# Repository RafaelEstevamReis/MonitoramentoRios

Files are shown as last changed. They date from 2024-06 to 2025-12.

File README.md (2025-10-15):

# MonitoramentoRios

Repositório do Projeto de Monitoramento de Rios

Acesse o sistema que monitora Rolante no Rio Grande do Sul: [Acessar](https://rios.bitcoineaqui.com.br/)

## Objetivo

Este repositório tem por objetivo desenvolver uma stack de Software e Hardware para monitoramento atmosférico, pluvial e fluvial, com o objetivo de publicar de forma aberta dados precisos a todos que precisarem.

## Arquitetura

O é Sistema altamente integrável, permitindo tanto o uso do Hardware desenvolvido aqui quanto integração de fontes externas, além de ser distribuído replicado em locais geograficamente afastados para redundância e proteção. 

Focando em baixo custo a Placa-mãe foi desenvolida pelo projeto para utilização de sensores amplamente disponíveis

### Detalhes do Hardware

Hardware baseado em ESP32 utilizando PCB customizada para o ambiente úmido da beira de rios mas compatível com DevKits como NodeMCU

Firmware baseado na Stack ESP-Home pela melhor curva de aprendizado de novos colaboradores

### Detalhes do Software

Backend redundante e integrado, recebe dados diretamente de estações, de servidor MQTT externo, de outros Backends, e integrações de sistemas externos

Frontend em Html/JS puro para leveza a simplicidade de treinamento e manutenção

## Agradecimentos Especiais

* A todas as doações em Bitcoin para o projeto [Bitcoin é Aqui](https://bitcoineaqui.com.br) que financiaram a pesquisa e desenvolvimento do projeto
* Ao [Geoge Silva](https://github.com/nitroxgas) por lançar a ideia e desenvolver o primeiro protótipo

## Posso usar o software ou hardware que este repositório desenvolve?

SIM!, mas com ressalvas.

O objetivo deste projeto é compartilhar informações, porém há muitas entidades que coletam os dados e os fecham, tornando-os inúteis para um amplo acesso.
Portanto, se você compartilha seus dados, você pode usar os nossos; se você restringe seus dados, você não pode usar os nossos.

Leia mais abaixo o texto completo do licenciamento antes de contribuir ou utilizar este repositório.

## Como replicar na minha cidade?

Você pode tanto replicar o sistema aqui desenvolvido por conta como integrar ao sistema já mantido pelo Projeto

Para integrar sua cidade no sistema já existente entre em contato com o [Bitcoin é Aqui](https://bitcoineaqui.com.br) ou com a [ACISA de Rolante](https://acisarolante.com/)

## Licença

Este repositório está licenciado sob uma dupla licença (`MIT` e `Licença Restrita`). Leia atenciosamente antes de contribuir e usar os dados gerados por estes softwares e hardwares.

A licença geral é MIT. No entanto, se você coleta, fornece e/ou processa dados de monitoramento atmosférico, manancial, fluvial, pluvial ou semelhantes, está sujeito às seguintes condições: Se os dados que você coleta são fechados, privados, compartilhados com limitações de acesso ou licenciamento, possuem mecanismos de controle de acesso, e/ou limitações na forma de acesso, então você não pode acessar, visualizar, compartilhar, utilizar, ou divulgar os dados coletados e gerados por este repositório e suas derivações. Nestes casos, você está sujeito à `Licença Restrita`.

Adicionalmente, se você é órgão governamental ou à serviço do serviço público, você precisa pedir autorização prévia para o uso dos dados.

### Licença Restrita

~~~
Termos de Uso da Licença Restrita

Esta licença estabelece os termos sob os quais os dados coletados e processados  podem ser acessados. Ao acessar ou utilizar estes dados, você concorda com os seguintes termos:

1. Proibição de Uso:

Os dados fornecidos por este repositório não podem ser utilizados para qualquer finalidade, seja ela comercial ou não comercial.

2. Proibição de Modificação:

Você não tem permissão para modificar, adaptar, ou criar obras derivadas dos dados fornecidos por este repositório.

3. Proibição de Redistribuição:

Você não pode redistribuir, compartilhar, publicar, ou de qualquer forma disponibilizar os dados a terceiros.

4. Proibição de Acesso Automatizado:

O acesso automatizado aos dados (por exemplo, via scripts, bots, ou outras ferramentas de automação) é estritamente proibido.

5. Proibição de Análise e Processamento:

Qualquer forma de análise ou processamento adicional dos dados coletados por este repositório é estritamente proibida.

6. Confidencialidade:

Você deve manter a confidencialidade dos dados acessados e não deve divulgar, publicar, ou de qualquer forma tornar públicos esses dados.

7. Penalidades

Qualquer violação dos termos desta licença pode resultar em medidas legais, incluindo, mas não se limitando a, ações civis e criminais.

8. Acordo

Ao acessar ou utilizar os dados fornecidos por este repositório, você reconhece que leu, entendeu e concorda em cumprir todos os termos desta licença. Se você não concorda com estes termos, não deve acessar ou utilizar os dados.
~~~

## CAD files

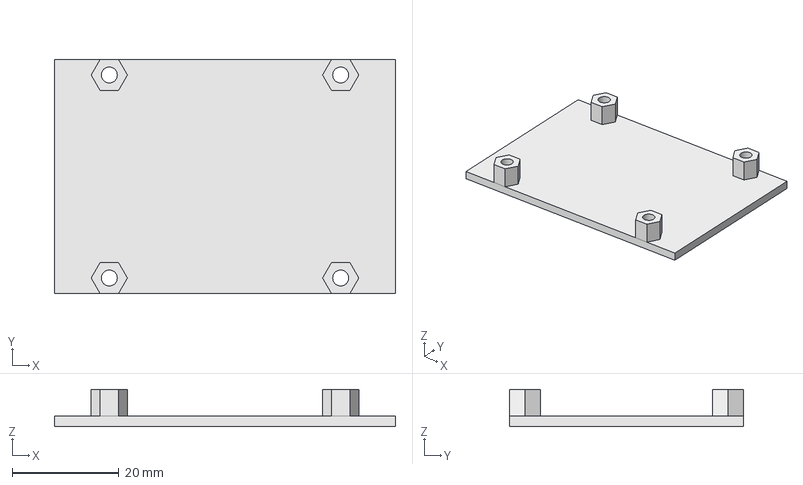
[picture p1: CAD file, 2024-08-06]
Hardware/Estação/Placa Mãe/Dev_1.1/Suporte/Suporte.FCStd
64.0 x 44.0 x 7.00 mm

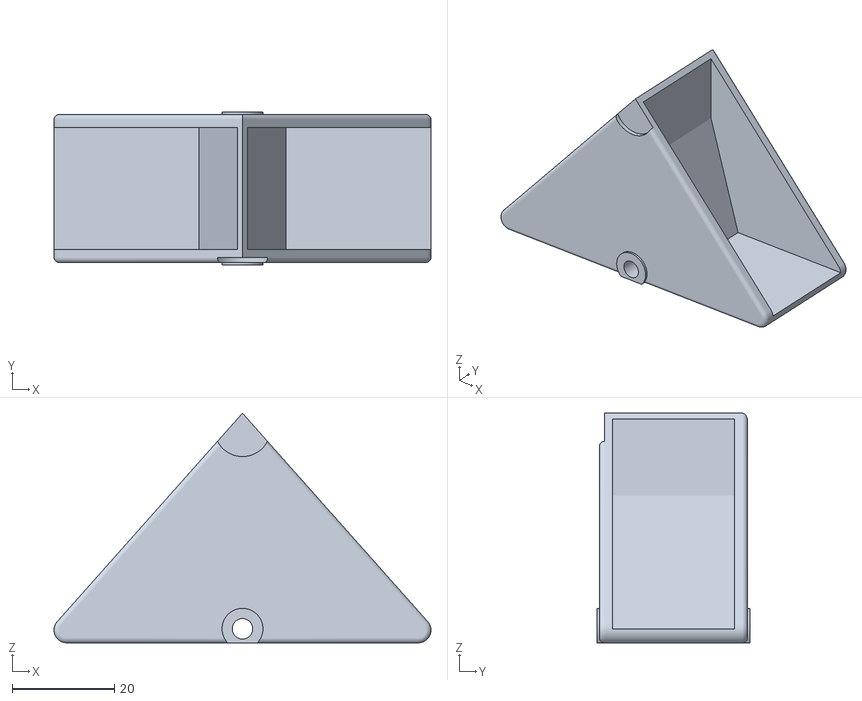
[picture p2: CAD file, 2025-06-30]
Hardware/Pluviômetro/3DP/Pluv_v0-Bucket.stl
73.9 x 30.0 x 45.0

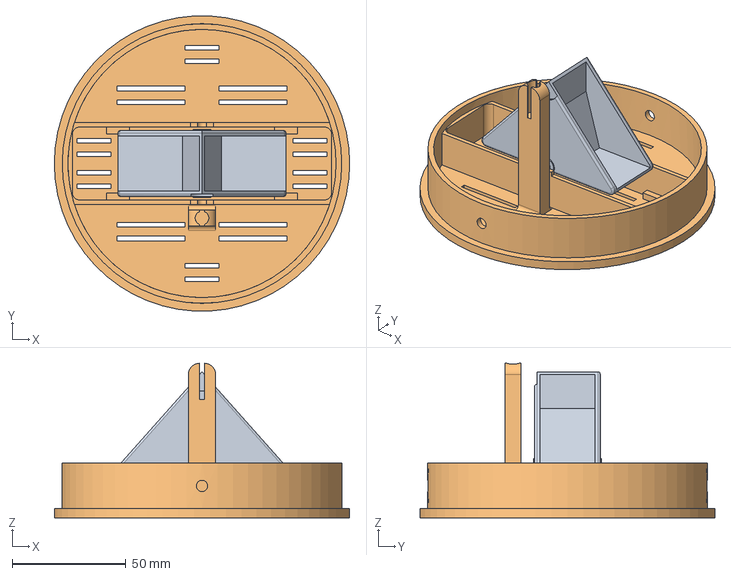
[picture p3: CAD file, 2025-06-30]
Hardware/Pluviômetro/3DP/Pluv_v0.FCStd
130.0 x 129.8 x 68.0 mm
Bucket
Base

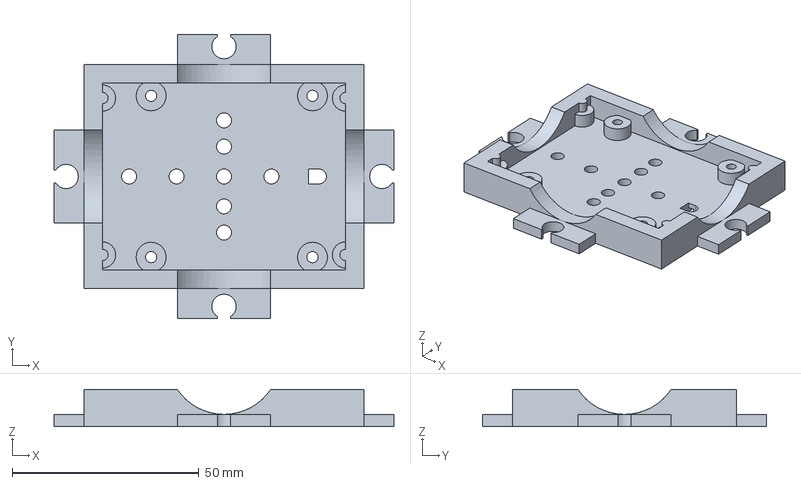
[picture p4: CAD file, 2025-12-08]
Montagem/Acessorios/SuportePlaca_v1.3.FCStd
91.0 x 76.0 x 10.0 mm

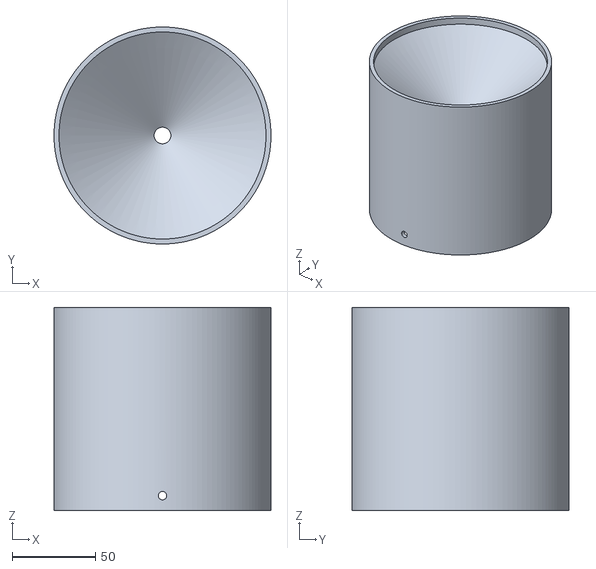
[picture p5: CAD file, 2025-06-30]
Hardware/Pluviômetro/3DP/Pluv_v0-Funnel.stl
130.0 x 130.0 x 121.8

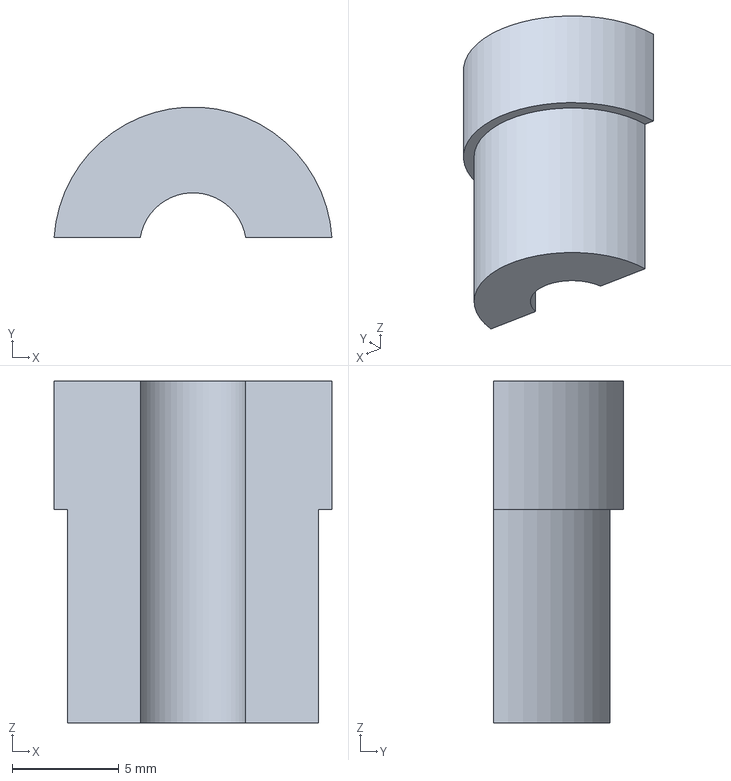
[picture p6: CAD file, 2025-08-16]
Montagem/Acessorios/SabotCabo.FCStd
13.0 x 6.10 x 16.0 mm

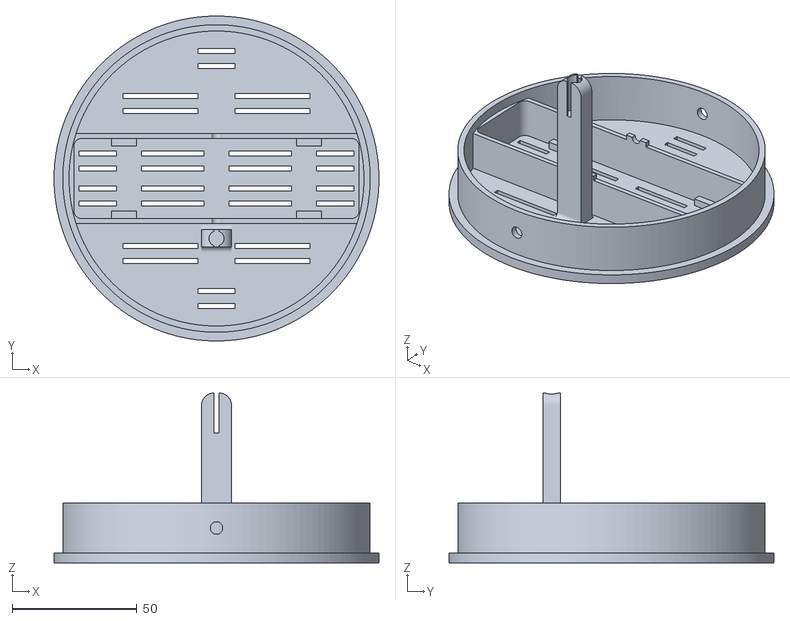
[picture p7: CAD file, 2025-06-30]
Hardware/Pluviômetro/3DP/Pluv_v0-Base.stl
130.0 x 130.0 x 68.0

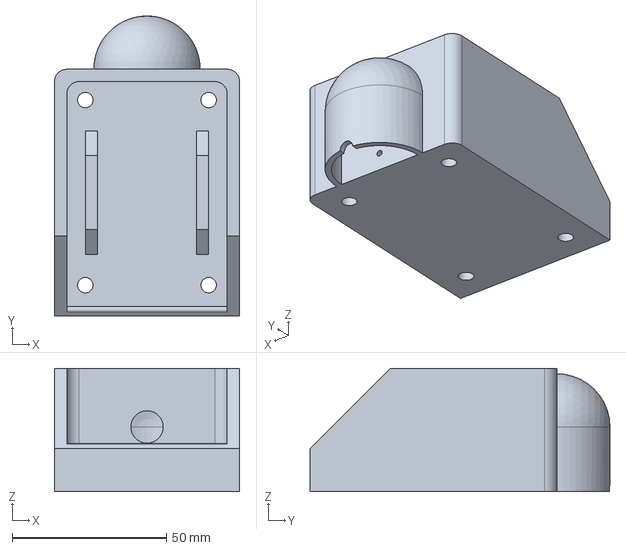
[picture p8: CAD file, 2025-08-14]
Montagem/Acessorios/SuporteBoia.FCStd
60.0 x 97.2 x 40.0 mm

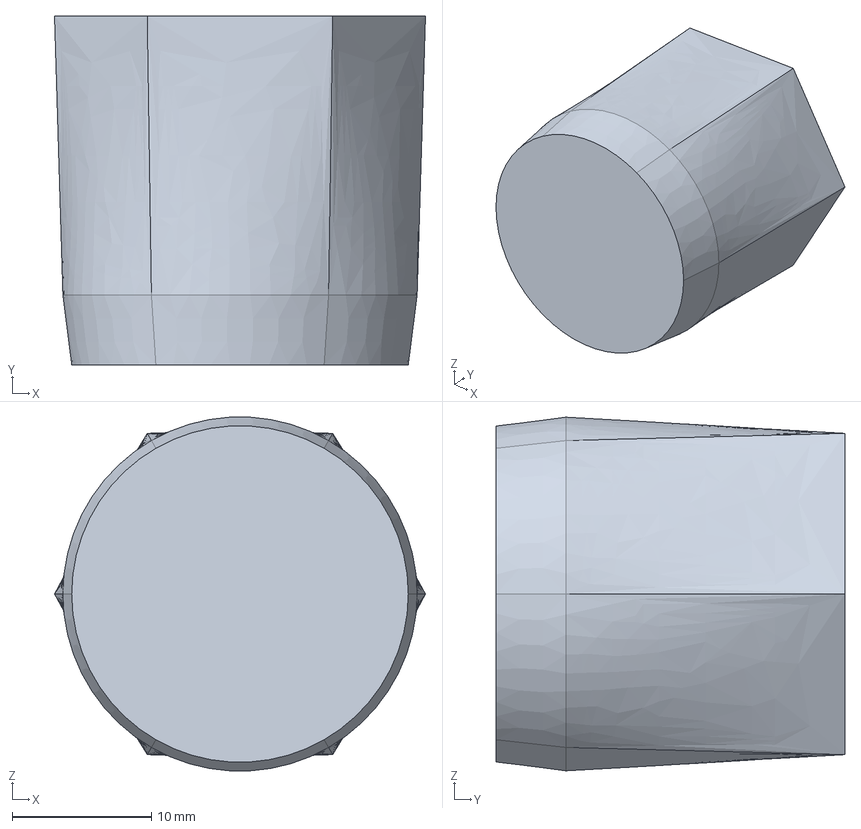
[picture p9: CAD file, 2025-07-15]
Montagem/Acessorios/Suporte_tubular_USS.FCStd
26.6 x 25.0 x 25.4 mm

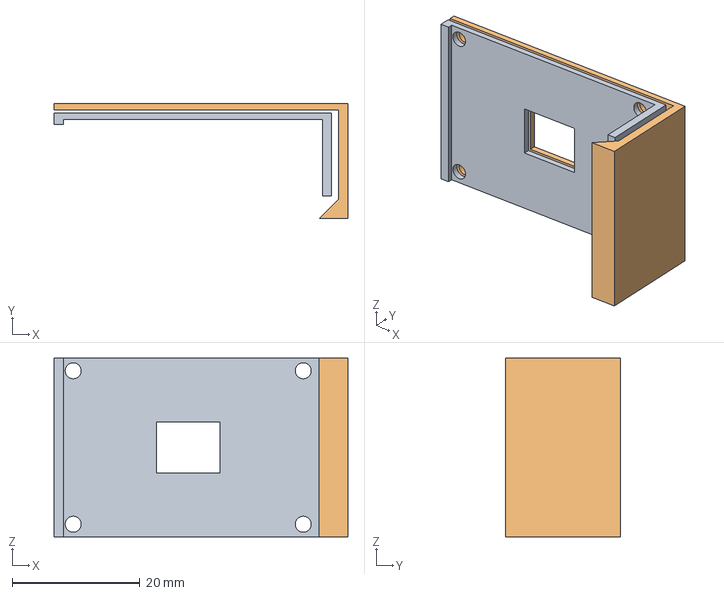
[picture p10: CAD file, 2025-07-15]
Montagem/Acessorios/Blindagem_SR04.FCStd
46.0 x 18.0 x 28.0 mm
Inner
Outter

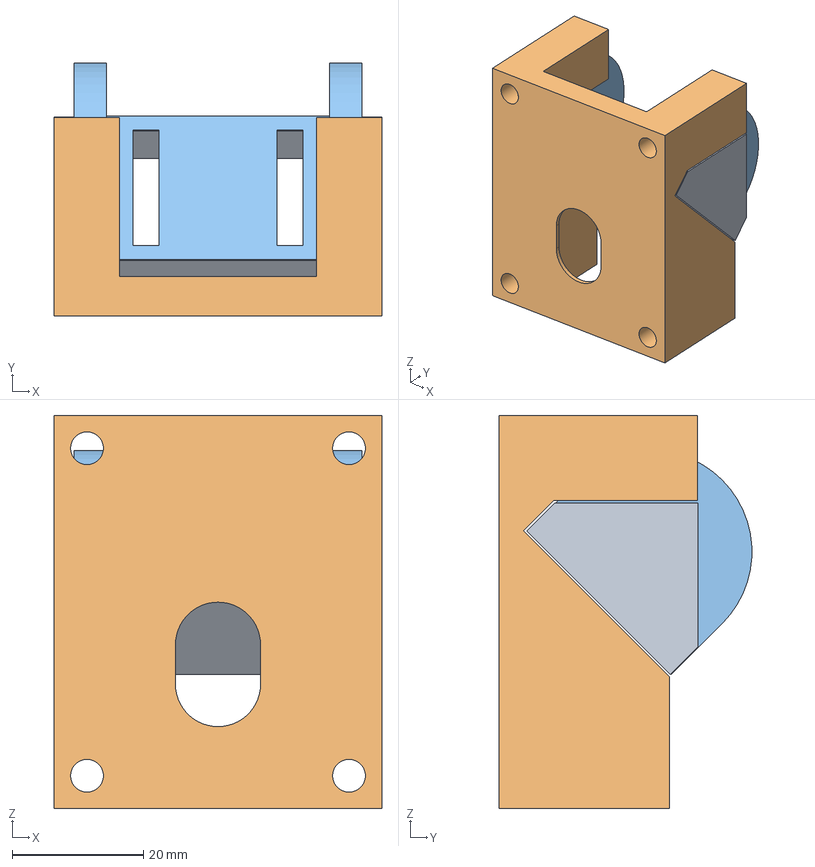
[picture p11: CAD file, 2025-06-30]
Montagem/Acessorios/SuporteEspCam.FCStd
50.0 x 38.6 x 60.0 mm
Holder
Front
PivotBottom

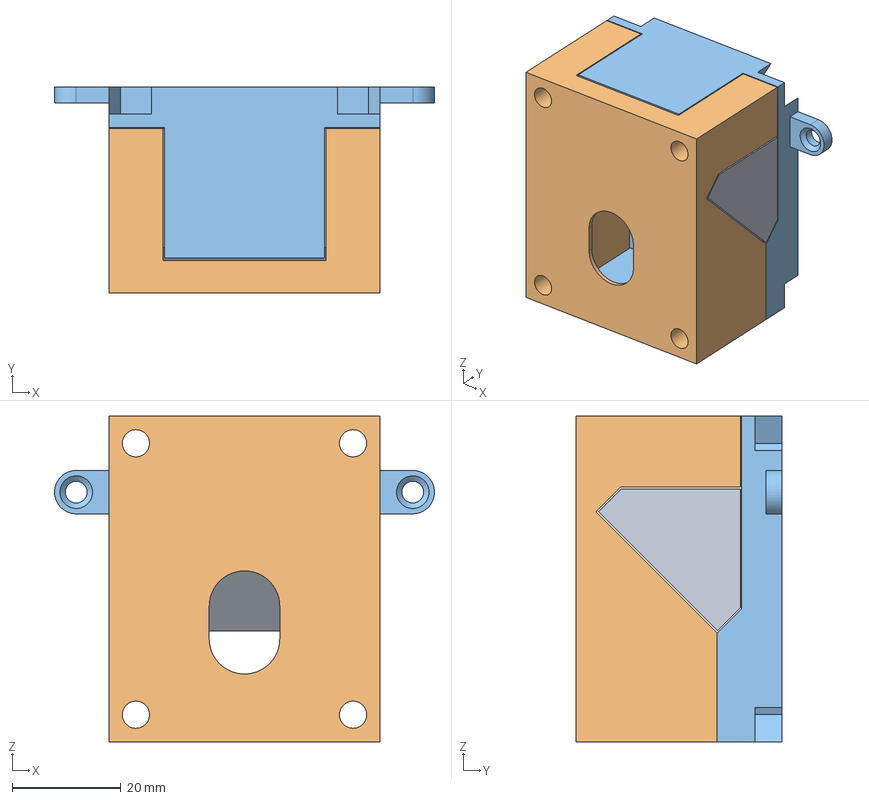
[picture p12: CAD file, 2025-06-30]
Montagem/Acessorios/SuporteEspCam_v1.FCStd
70.0 x 38.0 x 60.0 mm
Holder
Front
Back

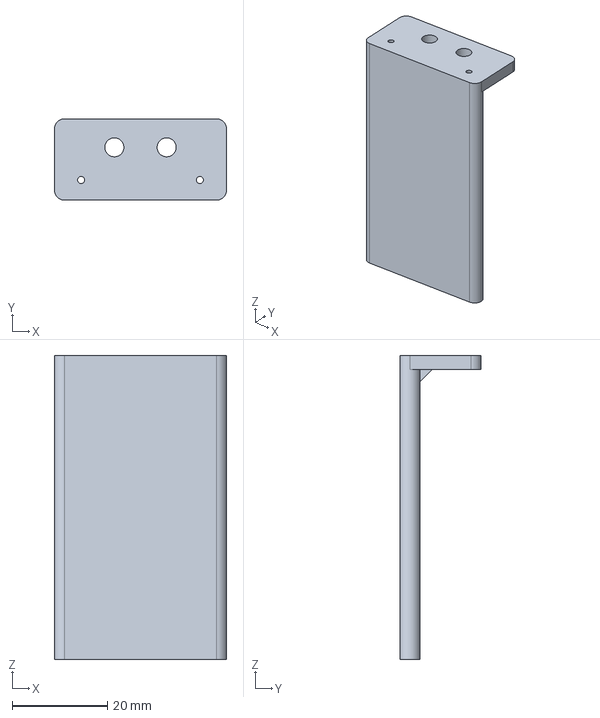
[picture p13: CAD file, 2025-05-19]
Montagem/Acessorios/SuporteSensorExterno.FCStd
36.3 x 17.1 x 64.0 mm

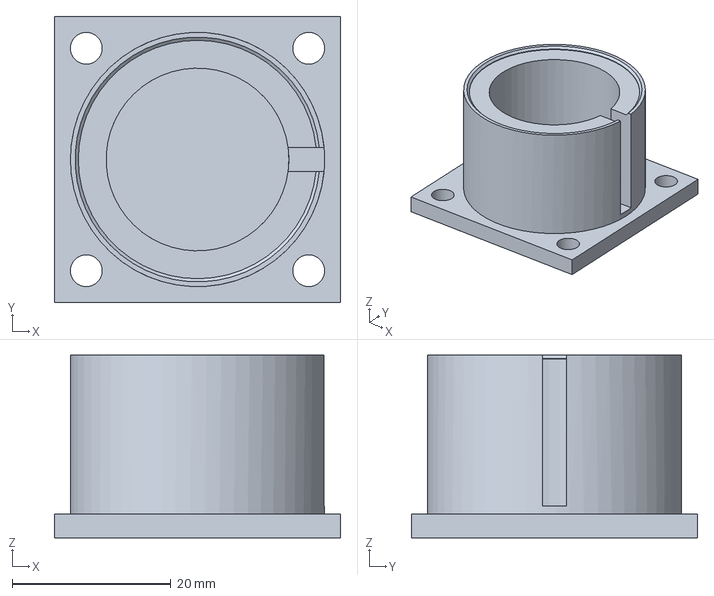
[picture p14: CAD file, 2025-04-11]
Montagem/Acessorios/SuporteFixoUSS.FCStd
36.0 x 36.0 x 23.0 mm

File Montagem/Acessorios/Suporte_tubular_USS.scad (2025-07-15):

$fn = 64;

tub_diameter = 23;
tub_length = 25;
tub_wall_thickness = 4;
sensor_diameter = 23;
wire_diameter = 3.5;
pin_diameter = 2;
// calculated
housing_diameter = 40;

opened = true;

difference() {
    union() {
        translate([0, tub_length-2, 0]) rotate([90,0,0]) 
            cylinder(h = tub_length+2, d = tub_diameter, center = true);
        cylinder(h = tub_diameter, d = housing_diameter, center = true, $fn=6);
    }
    // hollow
    translate([0, (tub_length + tub_diameter)/2, 0]) rotate([90,0,0]) 
        cylinder(h = tub_length + tub_diameter, d = tub_diameter - tub_wall_thickness, center = true, $fn=10);

    if(opened){
        // sensor
        cylinder(h = tub_diameter*1.1, d = sensor_diameter, center = true);
        // slit
        translate([0, -housing_diameter/2, 0]) 
            cube([wire_diameter, housing_diameter, tub_diameter*1.1], center=true);
    }else{
        // sensor
        translate([0, 0, -tub_diameter/2-1]) 
            cylinder(h = tub_diameter, d = sensor_diameter);
    }
    if(pin_diameter > 0){
      translate([0, tub_length-2, 0])rotate([0,90,0]) 
        #cylinder(h = tub_diameter*1.1, d = pin_diameter, center=true);
    }
}

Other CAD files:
Montagem/Acessorios/SuporteFonte4056.FCStd
Montagem/Acessorios/SuporteLoRa.FCStd
Montagem/Acessorios/SuporteLoRa_18650.FCStd
Montagem/Acessorios/SuporteLoRa_18650_v2.FCStd
Hardware/Estação/Placa Mãe/Dev_1.1/Suporte/Suporte.stl
Montagem/Acessorios/SuporteBateria18650.FCStd
Montagem/Acessorios/SuporteCaixa_190x150x90_Tubo.FCStd
Montagem/Acessorios/SuporteEspCam_v0.FCStd

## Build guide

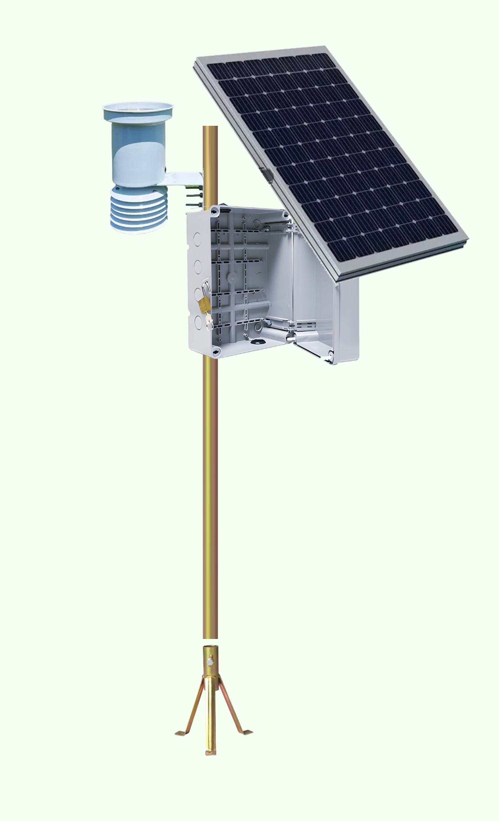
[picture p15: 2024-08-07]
Montagem/assets/geral-estação.png

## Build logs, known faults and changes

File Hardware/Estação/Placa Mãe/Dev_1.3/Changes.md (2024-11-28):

# Alterações da Versão Anterior

## Alterações

* Removido Rádio
* Adicionado pinos para Heltec

## Melhorias

* Separar LED externa
* Separar conector do vBat

## Notas

## ToDo

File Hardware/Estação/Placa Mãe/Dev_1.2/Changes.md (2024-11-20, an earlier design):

# Alterações da Versão Anterior

## Correções

* Alteração vBAT do GPIO04 para GPIO35
* Correção do Footprint dos capacitores, unificado em 0805
* Adicionado Pullup do DHT que estava faltando

## Melhorias

* Adicionadas 2 Leds de Status e uma Led no 3v3
* Alterado footprint do PC817 (precisa validar)
* Adicionar conector para USS
* Mudar footprint do diodo
* Mudar footprint dos botões

## Notas

## ToDo

* Mudar footprint do USB
* Mudar footprint do CP2102N
* Alterar furos da PCB para compabilidade com suportes de placa mãe
* Separar conector do vBat
* Separar LED externa

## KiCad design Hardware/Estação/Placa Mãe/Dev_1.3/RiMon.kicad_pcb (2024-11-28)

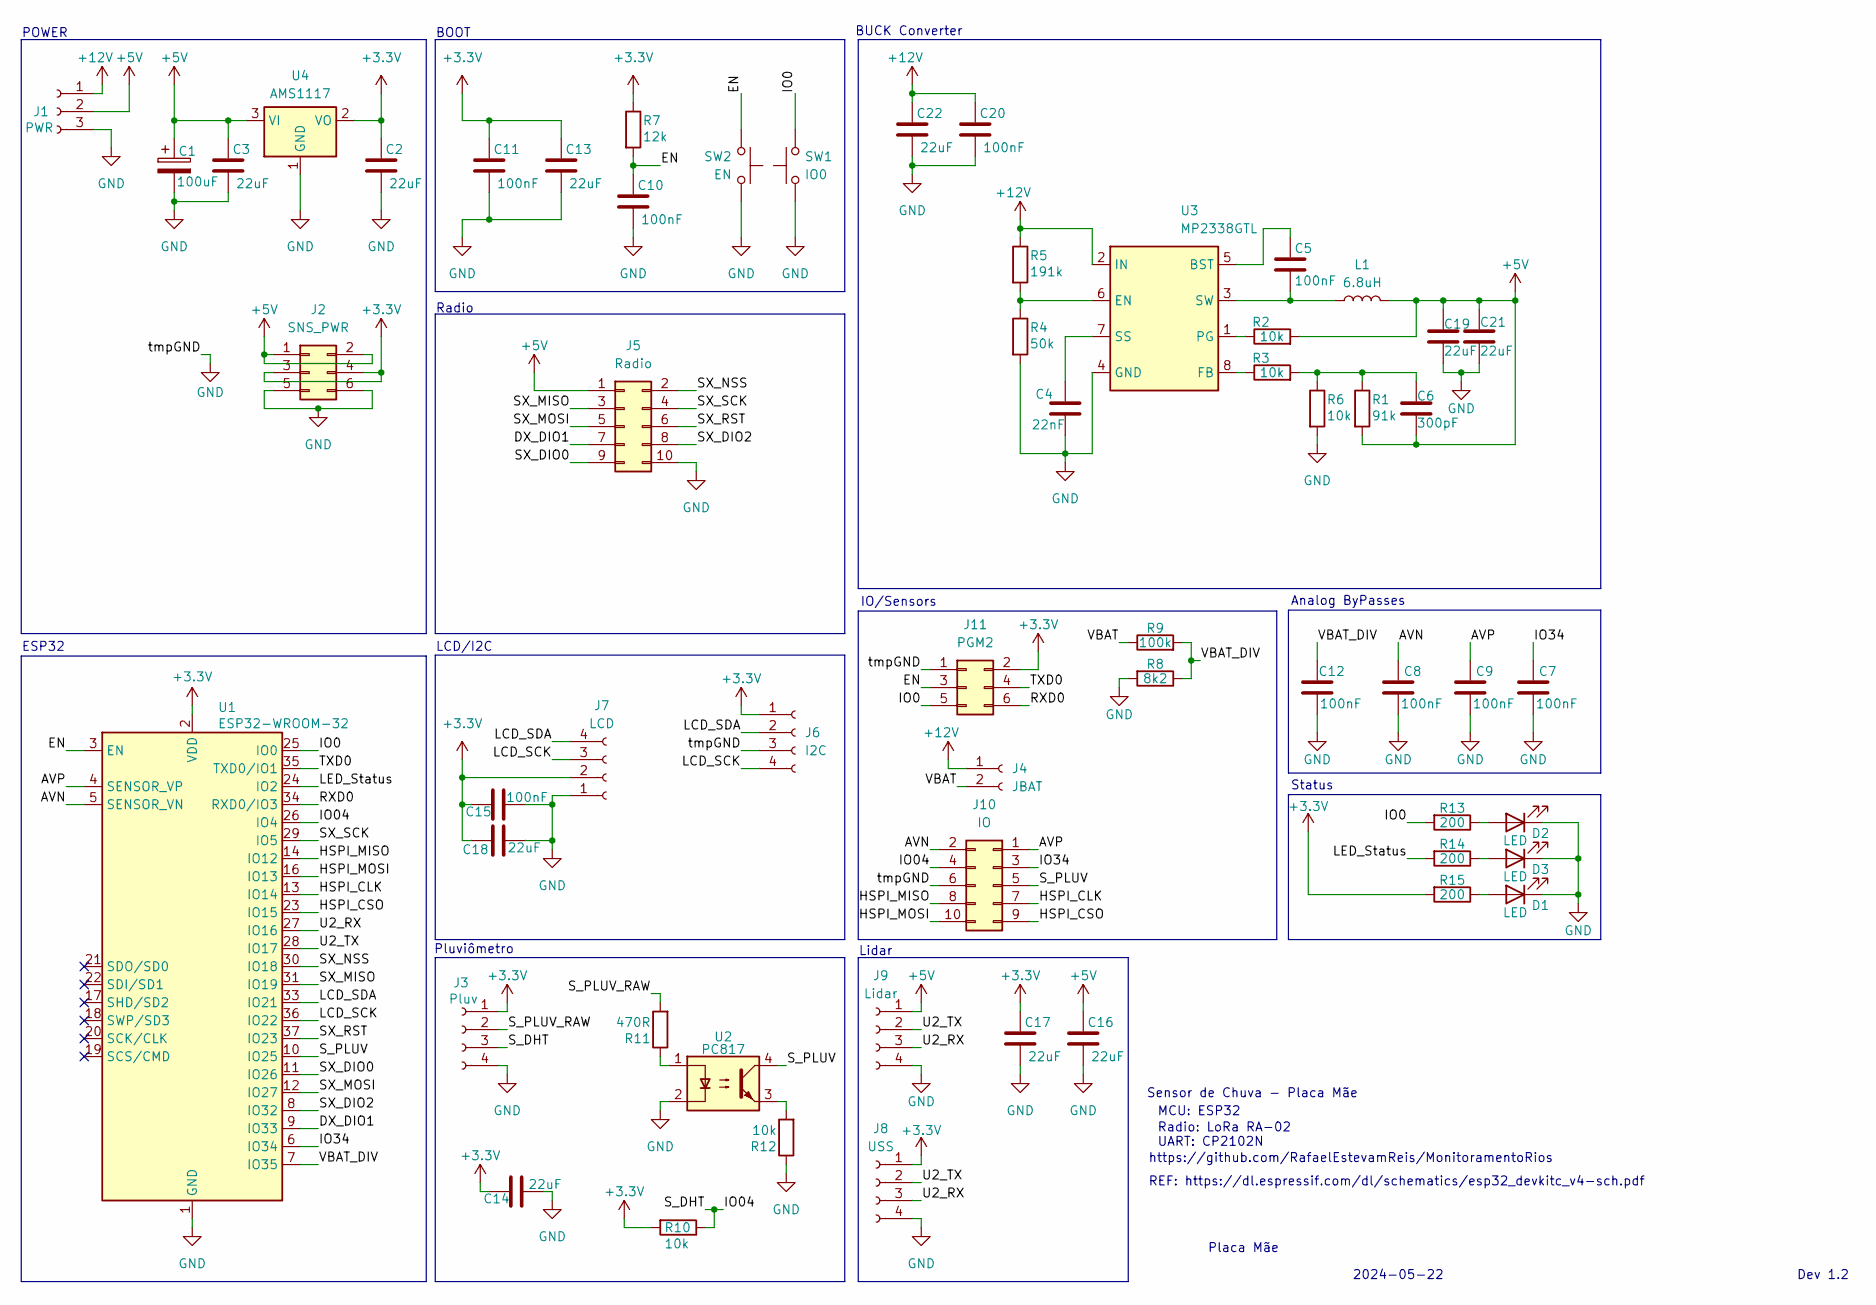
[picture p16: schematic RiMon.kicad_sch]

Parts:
C1: 100uF; CP_Elec_6.3x5.7
C2, C3, C14, C16, C17, C18: 22uF; C_0805_2012Metric_Pad1.18x1.45mm_HandSolder
C4: 22nF; C_0805_2012Metric_Pad1.18x1.45mm_HandSolder
C5, C7, C8, C9, C10, C11, C12, C15, C20: 100nF; C_0805_2012Metric_Pad1.18x1.45mm_HandSolder
C6: 300pF; C_0805_2012Metric_Pad1.18x1.45mm_HandSolder
C13, C19, C21, C22: 22uF; C_1206_3216Metric_Pad1.33x1.80mm_HandSolder
D1, D2, D3: LED; LED_D3.0mm
J1: PWR; TerminalBlock_Phoenix_MKDS-1,5-3-5.08_1x03_P5.08mm_Horizont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
J2: SNS_PWR; PinSocket_2x03_P2.54mm_Vertical
J3: Pluv; TerminalBlock_Phoenix_MKDS-1,5-4-5.08_1x04_P5.08mm_Horizont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
J4: JBAT; PinSocket_1x02_P2.54mm_Vertical
J5: Radio; PinSocket_2x05_P2.54mm_Vertical
J6: I2C; PinSocket_1x04_P2.54mm_Vertical
J7: LCD; PinSocket_1x04_P2.54mm_Vertical
J8: USS; PinSocket_1x04_P2.54mm_Vertical
J9: Lidar; JST_PH_B4B-PH-K_1x04_P2.00mm_Vertical
J10: IO; PinSocket_2x05_P2.54mm_Vertical
J11: PGM2; PinSocket_2x03_P2.54mm_Vertical
L1: 6.8uH; L_Wuerth_HCI-1040
R1: 91k; R_0805_2012Metric_Pad1.20x1.40mm_HandSolder
R2, R3, R6, R10, R12: 10k; R_0805_2012Metric_Pad1.20x1.40mm_HandSolder
R4: 50k; R_0805_2012Metric_Pad1.20x1.40mm_HandSolder
R5: 191k; R_0805_2012Metric_Pad1.20x1.40mm_HandSolder
R7: 12k; R_0805_2012Metric_Pad1.20x1.40mm_HandSolder
R8: 8k2; R_0805_2012Metric_Pad1.20x1.40mm_HandSolder
R9: 100k; R_0805_2012Metric_Pad1.20x1.40mm_HandSolder
R11: 470R; R_0805_2012Metric_Pad1.20x1.40mm_HandSolder
R13, R14, R15: 200; R_0805_2012Metric_Pad1.20x1.40mm_HandSolder
SW1: IO0; SW_Push_1P1T_NO_6x6mm_H9.5mm
SW2: EN; SW_Push_1P1T_NO_6x6mm_H9.5mm
U1: ESP32-WROOM-32
U2: PC817; SSO-4_6.7x5.1mm_P2.54mm_Clearance8mm
U3: MP2338GTL; SOT-583-8
U4: AMS1117; SOT-223-3_TabPin2

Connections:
+3.3V: C2.1, C11.1, C13.1, C14.2, C15.2, C17.1, C18.1, J2.3, J2.4, J3.1, J6.1, J7.2, J8.1, J11.2, R7.1, R10.2, R15.2, U1.2 (VDD), U4.2 (VO)
+5V: C1.1, C3.1, C6.2, C16.1, C19.1, C21.1, J1.2, J2.1, J2.2, J5.1, J9.1, L1.2, R1.2, R2.2, U4.3 (VI)
+12V: C20.1, C22.1, J1.1, J4.1, R5.1, U3.2 (IN)
/AVN: C8.2, J10.2, U1.5 (SENSOR_VN)
/AVP: C9.2, J10.1, U1.4 (SENSOR_VP)
/DX_DIO1: J5.7, U1.9 (IO33)
/EN: C10.1, J11.3, R7.2, SW2.2, U1.3 (EN)
/HSPI_CLK: J10.7, U1.13 (IO14)
/HSPI_CSO: J10.9, U1.23 (IO15)
/HSPI_MISO: J10.8, U1.14 (IO12)
/HSPI_MOSI: J10.10, U1.16 (IO13)
/IO0: J11.5, R13.2, SW1.2, U1.25 (IO0)
/IO04: J3.3, J10.4, R10.1, U1.26 (IO4)
/IO34: C7.2, J10.3, U1.6 (IO34)
/LCD_SCK: J6.4, J7.3, U1.36 (IO22)
/LCD_SDA: J6.2, J7.4, U1.33 (IO21)
/LED_Status: R14.2, U1.24 (IO2)
/RXD0: J11.6, U1.34 (RXD0/IO3)
/SX_DIO0: J5.9, U1.11 (IO26)
/SX_DIO2: J5.8, U1.8 (IO32)
/SX_MISO: J5.3, U1.31 (IO19)
/SX_MOSI: J5.5, U1.12 (IO27)
/SX_NSS: J5.2, U1.30 (IO18)
/SX_RST: J5.6, U1.37 (IO23)
/SX_SCK: J5.4, U1.29 (IO5)
/S_PLUV: J10.5, U1.10 (IO25), U2.4
/S_PLUV_RAW: J3.2, R11.2
/TXD0: J11.4, U1.35 (TXD0/IO1)
/U2_RX: J8.3, J9.3, U1.27 (IO16)
/U2_TX: J8.2, J9.2, U1.28 (IO17)
/VBAT: J4.2, R9.1
/VBAT_DIV: C12.2, R8.1, R9.2, U1.7 (IO35)
GND: C1.2, C2.2, C3.2, C4.2, C7.1, C8.1, C9.1, C10.2, C11.2, C12.1, C13.2, C14.1, C15.1, C16.2, C17.2, C18.2, C19.2, C20.2, C21.2, C22.2, D1.1 (K), D2.1 (K), D3.1 (K), J1.3, J2.5, J2.6, J3.4, J5.10, J6.3, J7.1, J8.4, J9.4, J10.6, J11.1, R4.2, R6.2, R8.2, R12.1, SW1.1, SW2.1, U1.1 (GND), U1.15 (GND), U1.38 (GND), U1.39 (GND), U2.2, U3.4 (GND), U4.1 (GND)
unnamed: C6.1, R1.1, R3.2, R6.1
unnamed: D1.2 (A), R15.1
unnamed: D2.2 (A), R13.1
unnamed: D3.2 (A), R14.1
unnamed: R11.1, U2.1
unnamed: R12.2, U2.3
unnamed: C5.1, U3.5 (BST)
unnamed: R4.1, R5.2, U3.6 (EN)
unnamed: R3.1, U3.8 (FB)
unnamed: R2.1, U3.1 (PG)
unnamed: C4.1, U3.7 (SS)
unnamed: C5.2, L1.1, U3.3 (SW)

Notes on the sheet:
IO/Sensors
BOOT
Pluviômetro
Lidar
Status
Placa Mãe
https://github.com/RafaelEstevamReis/MonitoramentoRios
2024-05-22
LCD/I2C
Dev 1.2
Radio: LoRa RA-02
Analog ByPasses
UART: CP2102N
Radio
MCU: ESP32
BUCK Converter
Sensor de Chuva - Placa Mãe
POWER
ESP32
REF: https://dl.espressif.com/dl/schematics/esp32_devkitc_v4-sch.pdf

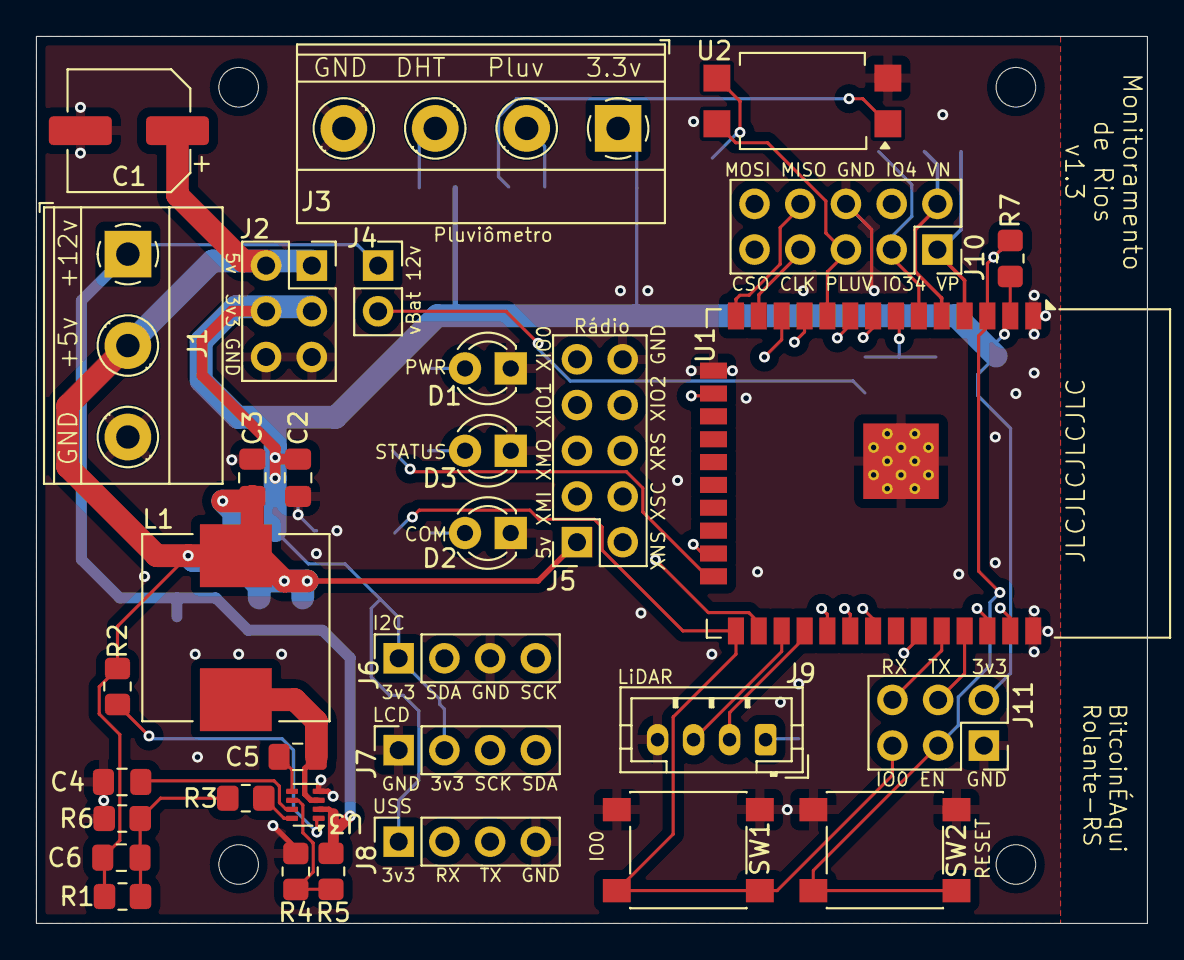
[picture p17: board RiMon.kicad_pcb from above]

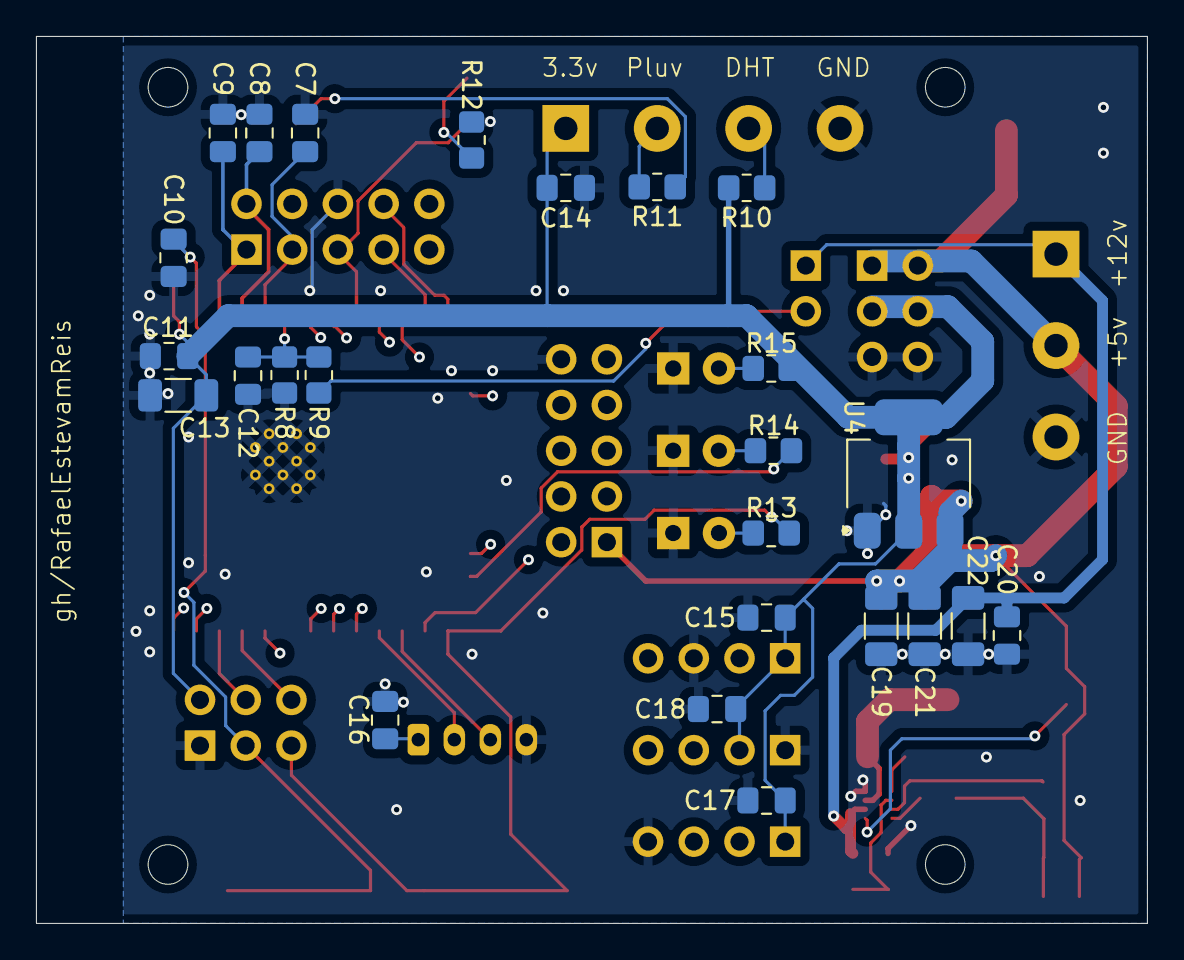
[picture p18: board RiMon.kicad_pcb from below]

Board: 4 copper layers, 61.7 x 49.3 mm, 58 parts (25 on the bottom side), 45 nets.

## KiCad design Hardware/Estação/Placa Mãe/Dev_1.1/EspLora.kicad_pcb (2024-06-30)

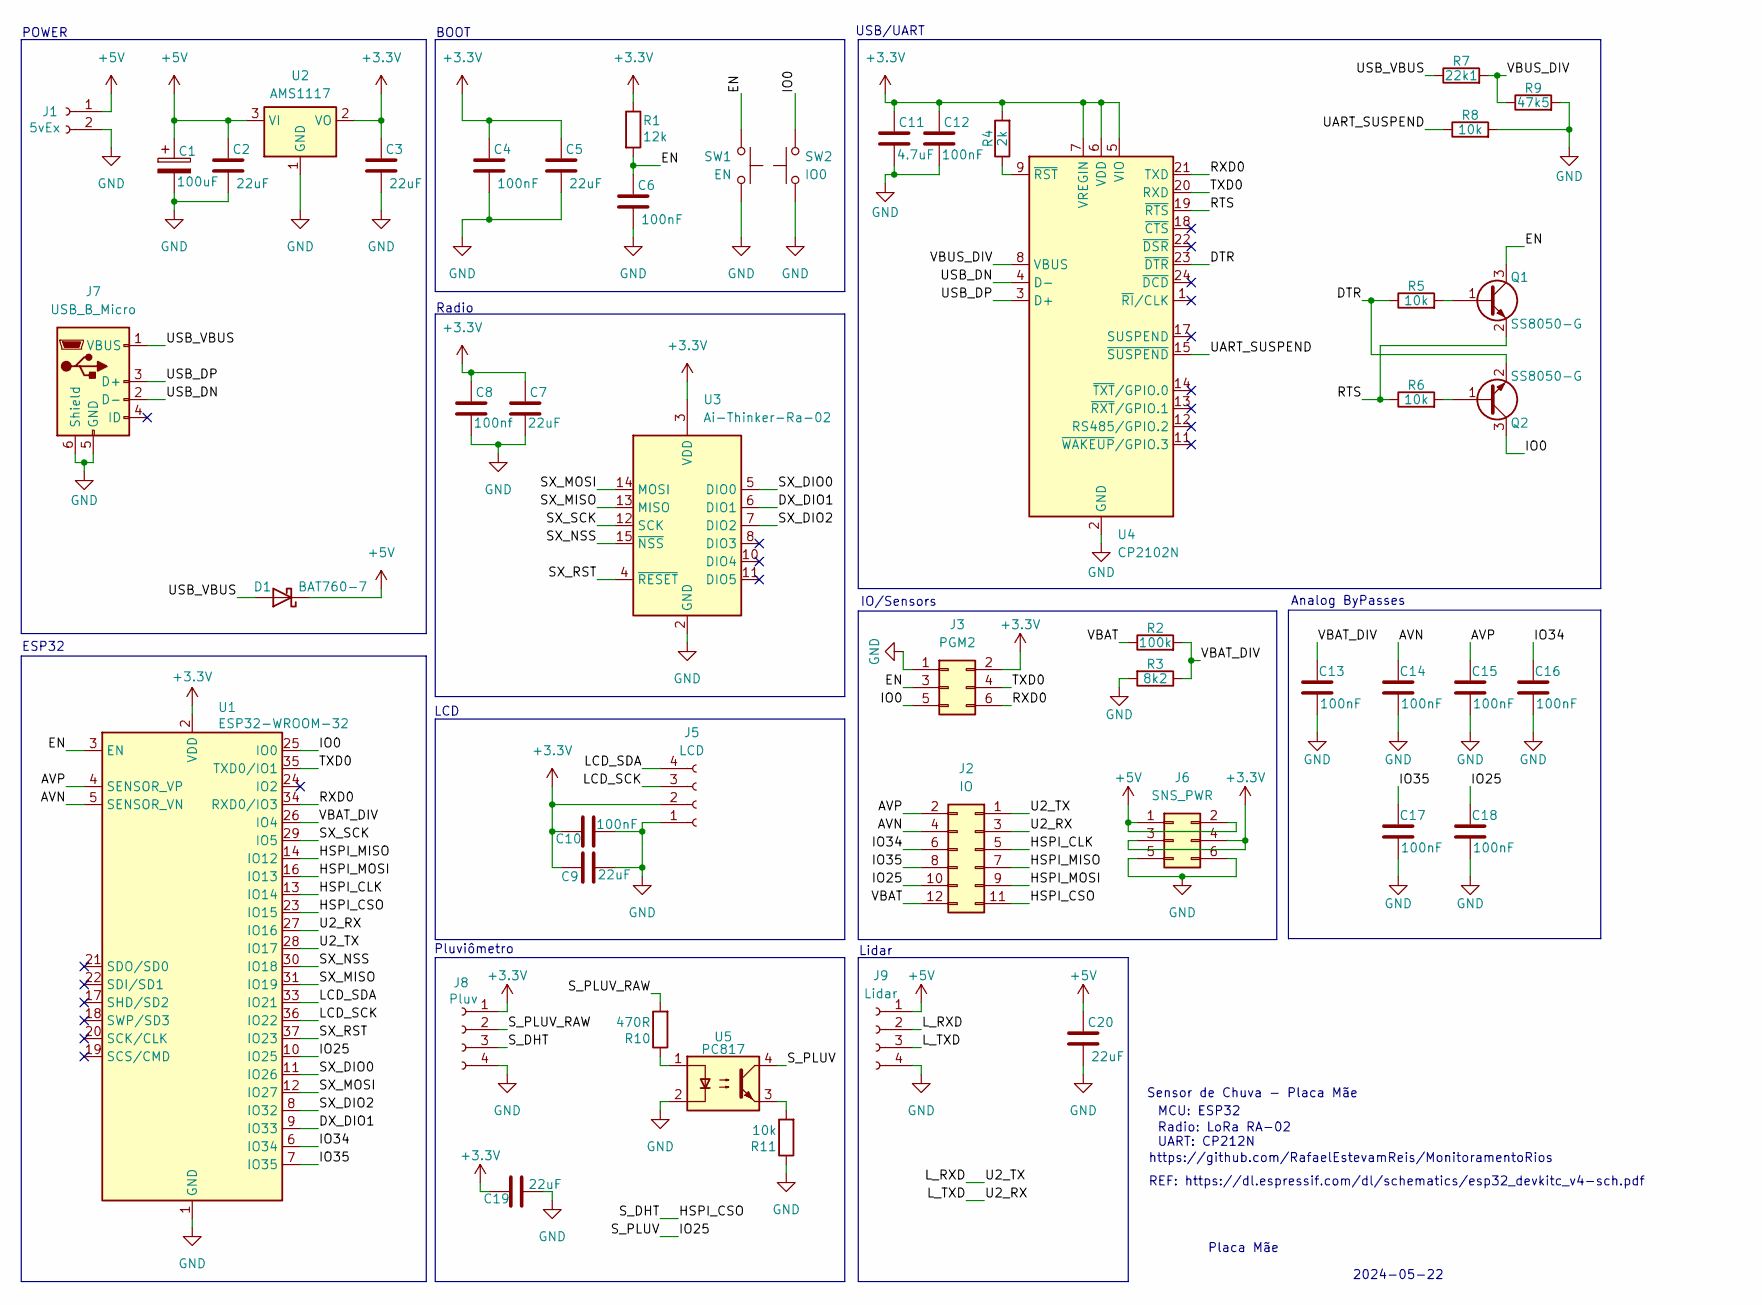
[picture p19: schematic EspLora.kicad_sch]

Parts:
C1: 100uF; CP_Elec_6.3x5.7
C2, C3, C5, C7, C9, C20: 22uF; C_1206_3216Metric_Pad1.33x1.80mm_HandSolder
C4, C6, C10, C12, C13, C14, C15, C16, C17, C18: 100nF; C_0805_2012Metric_Pad1.18x1.45mm_HandSolder
C8: 100nf; C_0805_2012Metric_Pad1.18x1.45mm_HandSolder
C11: 4.7uF; C_1206_3216Metric_Pad1.33x1.80mm_HandSolder
C19: 22uF; C_0805_2012Metric_Pad1.18x1.45mm_HandSolder
D1: BAT760-7; D_SOD-323_HandSoldering
J1: 5vEx; TerminalBlock_Phoenix_MKDS-1,5-2-5.08_1x02_P5.08mm_Horizont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
J2: IO; PinSocket_2x06_P2.54mm_Vertical
J3: PGM2; PinSocket_2x03_P2.54mm_Vertical
J5: LCD; PinSocket_1x04_P2.54mm_Vertical
J6: SNS_PWR; PinSocket_2x03_P2.54mm_Vertical
J7: USB_B_Micro; USB_Micro-B_GCT_USB3076-30-A
J8: Pluv; TerminalBlock_Phoenix_MKDS-1,5-4-5.08_1x04_P5.08mm_Horizont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
J9: Lidar; JST_PH_B4B-PH-K_1x04_P2.00mm_Vertical
Q1, Q2: SS8050-G; SOT-23
R1: 12k; R_0805_2012Metric_Pad1.20x1.40mm_HandSolder
R2: 100k; R_0805_2012Metric_Pad1.20x1.40mm_HandSolder
R3: 8k2; R_0805_2012Metric_Pad1.20x1.40mm_HandSolder
R4: 2k; R_0805_2012Metric_Pad1.20x1.40mm_HandSolder
R5, R6, R8, R11: 10k; R_0805_2012Metric_Pad1.20x1.40mm_HandSolder
R7: 22k1; R_0805_2012Metric_Pad1.20x1.40mm_HandSolder
R9: 47k5; R_0805_2012Metric_Pad1.20x1.40mm_HandSolder
R10: 470R; R_0805_2012Metric_Pad1.20x1.40mm_HandSolder
SW1: EN; SW_Push_1P1T_NO_CK_KMR2
SW2: IO0; SW_Push_1P1T_NO_CK_KMR2
U1: ESP32-WROOM-32
U2: AMS1117; SOT-223-3_TabPin2
U3: Ai-Thinker-Ra-02; Ai-Thinker-Ra-01-LoRa
U4: CP2102N; QFN-24-1EP_4x4mm_P0.5mm_EP2.6x2.6mm
U5: PC817; SOP-4_3.8x4.1mm_P2.54mm

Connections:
+3.3V: C3.1, C4.1, C5.1, C7.1, C8.1, C9.1, C10.2, C11.1, C12.1, C19.2, J3.2, J5.2, J6.3, J6.4, J8.1, R1.1, R4.2, U1.2 (VDD), U2.2 (VO), U3.3 (VDD), U4.5 (VIO), U4.6 (VDD), U4.7 (VREGIN)
+5V: C1.1, C2.1, C20.1, D1.1 (K), J1.1, J6.1, J6.2, J9.1, U2.3 (VI)
/AVN: C14.2, J2.4, U1.5 (SENSOR_VN)
/AVP: C15.2, J2.2, U1.4 (SENSOR_VP)
/DTR: Q2.2 (E), R5.1, U4.23 (~DTR)
/DX_DIO1: U1.9 (IO33), U3.6 (DIO1)
/EN: C6.1, J3.3, Q1.3 (C), R1.2, SW1.2, U1.3 (EN)
/HSPI_CLK: J2.5, U1.13 (IO14)
/HSPI_CSO: J2.11, J8.3, U1.23 (IO15)
/HSPI_MISO: J2.7, U1.14 (IO12)
/HSPI_MOSI: J2.9, U1.16 (IO13)
/IO0: J3.5, Q2.3 (C), SW2.2, U1.25 (IO0)
/IO25: C18.2, J2.10, U1.10 (IO25), U5.4
/IO34: C16.2, J2.6, U1.6 (IO34)
/IO35: C17.2, J2.8, U1.7 (IO35)
/LCD_SCK: J5.3, U1.36 (IO22)
/LCD_SDA: J5.4, U1.33 (IO21)
/L_RXD: J2.1, J9.2, U1.28 (IO17)
/L_TXD: J2.3, J9.3, U1.27 (IO16)
/RTS: Q1.2 (E), R6.1, U4.19 (~RTS)
/RXD0: J3.6, U1.34 (RXD0/IO3), U4.21 (TXD)
/SX_DIO0: U1.11 (IO26), U3.5 (DIO0)
/SX_DIO2: U1.8 (IO32), U3.7 (DIO2)
/SX_MISO: U1.31 (IO19), U3.13 (MISO)
/SX_MOSI: U1.12 (IO27), U3.14 (MOSI)
/SX_NSS: U1.30 (IO18), U3.15 (~NSS)
/SX_RST: U1.37 (IO23), U3.4 (~RESET)
/SX_SCK: U1.29 (IO5), U3.12 (SCK)
/S_PLUV_RAW: J8.2, R10.2
/TXD0: J3.4, U1.35 (TXD0/IO1), U4.20 (RXD)
/UART_SUSPEND: R8.1, U4.15 (~SUSPEND)
/USB_DN: J7.2 (D-), U4.4 (D-)
/USB_DP: J7.3 (D+), U4.3 (D+)
/USB_VBUS: D1.2 (A), J7.1 (VBUS), R7.1
/VBAT: J2.12, R2.1
/VBAT_DIV: C13.2, R2.2, R3.1, U1.26 (IO4)
/VBUS_DIV: R7.2, R9.1, U4.8 (VBUS)
GND: C1.2, C2.2, C3.2, C4.2, C5.2, C6.2, C7.2, C8.2, C9.2, C10.1, C11.2, C12.2, C13.1, C14.1, C15.1, C16.1, C17.1, C18.1, C19.1, C20.2, J1.2, J3.1, J5.1, J6.5, J6.6, J7.5 (GND), J7.6 (Shield), J8.4, J9.4, R3.2, R8.2, R9.2, R11.1, SW1.1, SW2.1, U1.1 (GND), U1.15 (GND), U1.38 (GND), U1.39 (GND), U2.1 (GND), U3.1 (GND), U3.2 (GND), U3.9 (GND), U3.16 (GND), U4.2 (GND), U4.25 (GND), U5.2
unnamed: Q1.1 (B), R5.2
unnamed: Q2.1 (B), R6.2
unnamed: R10.1, U5.1
unnamed: R11.2, U5.3
unnamed: R4.1, U4.9 (~RST)

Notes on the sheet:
IO/Sensors
BOOT
Pluviômetro
Lidar
Placa Mãe
https://github.com/RafaelEstevamReis/MonitoramentoRios
2024-05-22
LCD
Radio: LoRa RA-02
Analog ByPasses
UART: CP212N
Radio
MCU: ESP32
USB/UART
Sensor de Chuva - Placa Mãe
POWER
ESP32
REF: https://dl.espressif.com/dl/schematics/esp32_devkitc_v4-sch.pdf

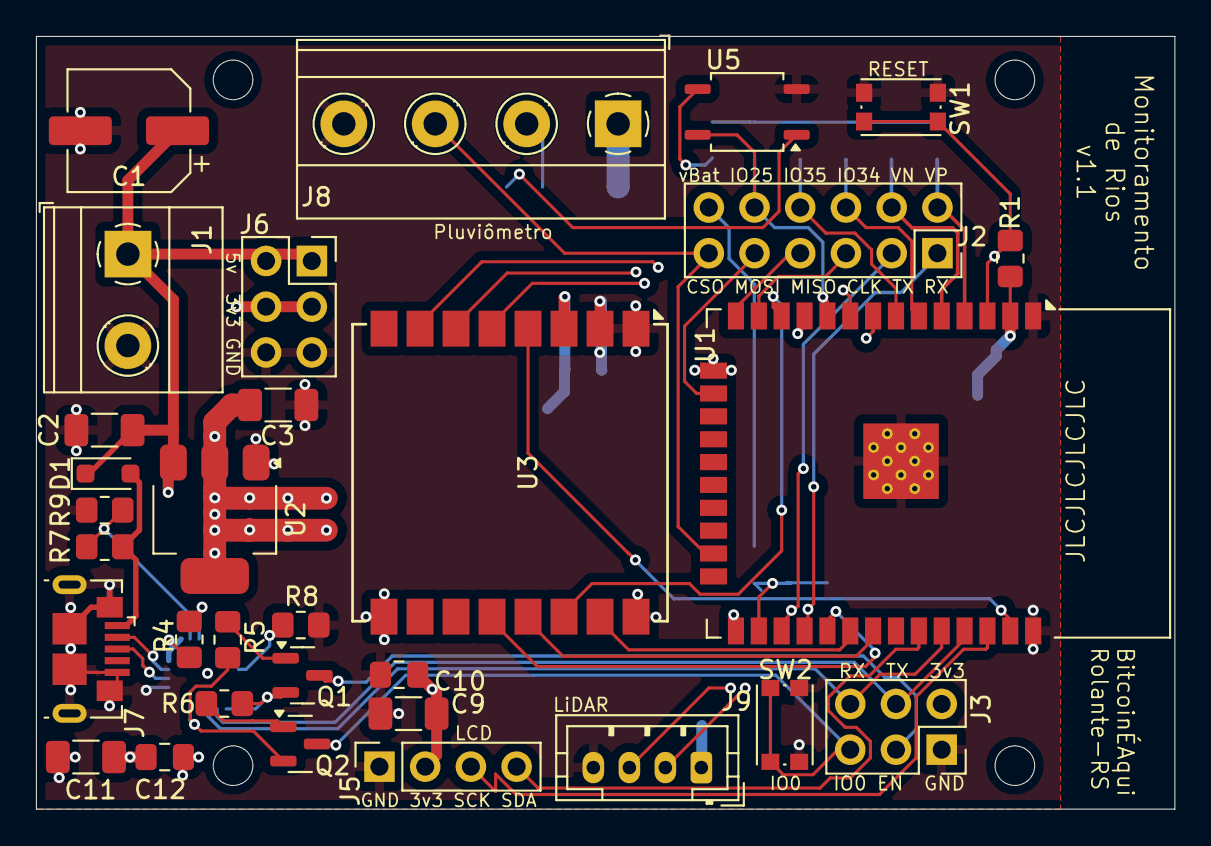
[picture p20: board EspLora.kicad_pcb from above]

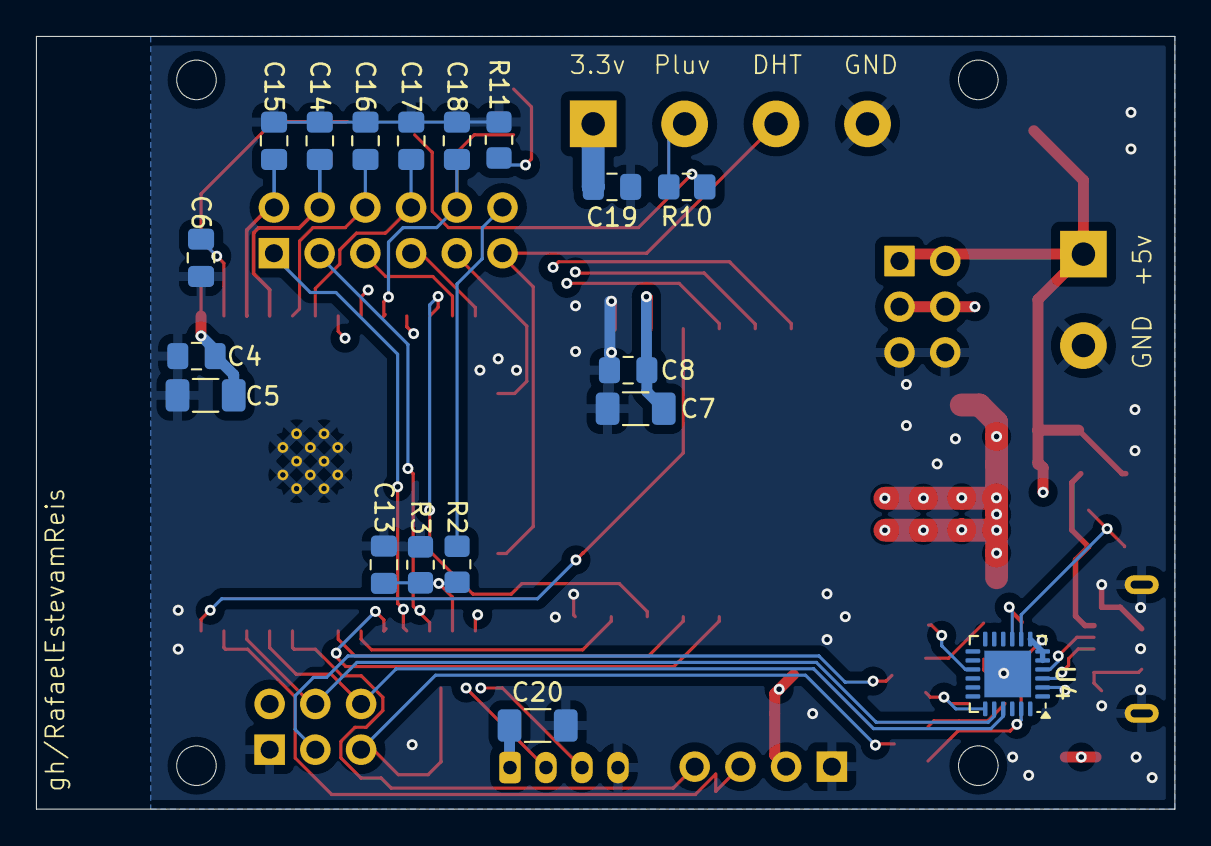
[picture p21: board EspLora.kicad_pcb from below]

Board: 4 copper layers, 63.2 x 42.9 mm, 49 parts (18 on the bottom side), 43 nets.

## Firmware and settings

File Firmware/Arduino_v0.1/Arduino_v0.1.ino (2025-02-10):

#include <WiFi.h>
#include <DHT.h>
#include <HTTPClient.h>
#include "dados_estacao.h"

// Endpoint
const char* endpoint1 = "https://monitorarios.xyz/Up/upload";
const char* endpoint2 = nullptr; 

extern "C" {
  uint8_t temprature_sens_read();
}

// Objetos
DHT dht(DHT_PIN, DHT_TYPE);

float readAdcVoltage() {
  int rawValue = analogRead(ADC_PIN);
  return ((float)rawValue / 4095.0) * 3.3; // Supondo referência de 3.3V
}
float vBatToPercent(float vBat){
  if(vBat == NAN) return NAN;

  // Max/Min
  float max = vBatTable[0][1];
  float min = vBatTable[vBatTableRows-1][1];

  if(vBat >= max) return 100;
  if(vBat <= min) return 0;

  // Percorre a tabela até a penúltima linha (pois estamos comparando a linha atual com a próxima)
  for (int i = 0; i < vBatTableRows - 1; i++) {
    float currRow_vL = vBatTable[i+1][1];
    float currRow_vH = vBatTable[i][1];

    if (vBat >= currRow_vL && vBat <= currRow_vH) {
      return mapfloat(vBat, currRow_vL, currRow_vH, vBatTable[i+1][0], vBatTable[i][0]);
    }
  }
  return 0;
}

/* WIFI */

void connectToWiFi() {
  if (WiFi.status() == WL_CONNECTED) return;
  // Avisa início do WIFI
  digitalWrite(LED_STATUS, HIGH);
  delay(100);
  digitalWrite(LED_STATUS, LOW);
  delay(200);
  digitalWrite(LED_STATUS, HIGH);
  delay(100);
  digitalWrite(LED_STATUS, LOW);

  for (int i = 0; i < num_wifi_networks; i++) {
    Serial.print("\nConectando a ");
    Serial.print(wifi_ssids[i]);
    WiFi.begin(wifi_ssids[i], wifi_passwords[i]);

    int retry_count = 0;
    while (WiFi.status() != WL_CONNECTED && retry_count < 10) {
      // Avisa conexão...
      digitalWrite(LED_STATUS, HIGH);
      delay(300);
      digitalWrite(LED_STATUS, LOW);
      delay(700);

      Serial.print(".");
      retry_count++;
    }

    if (WiFi.status() == WL_CONNECTED) {
      Serial.println("\nConectado com sucesso!");
      return;
    }
  }
  Serial.println("\nFalha ao conectar a todas as redes WiFi.");
}
void disconnectWiFi() {
  Serial.println("Desconectando do WiFi...");
  WiFi.disconnect();
}

/* DATA UPLOAD */
void sendData() {
  if (WiFi.status() != WL_CONNECTED) {
    Serial.println("WiFi desconectado - DATA SKIP");
    return;
  }

  float vBatVoltage = readAdcVoltage() * vBatCal;
  float vBatPercent = vBatToPercent(vBatVoltage);
  float temperature = dht.readTemperature();
  float humidity = dht.readHumidity();
  float intTemp_celsius = readInternalTemp();
  
  String payload = "{";
  // Sensors
  if (isnan(vBatVoltage)) Serial.println("Erro ao ler a vBat!");
  else {
    payload += "\"TensaoBateria\": " + String(vBatVoltage) + ", ";
    payload += "\"PercentBateria\": " + String(vBatPercent) + ", ";
  }
  
  if (isnan(temperature)) Serial.println("Erro ao ler a temperatura!");
  else payload += "\"TemperaturaAr\": " + String(temperature) + ", ";

  if (isnan(humidity)) Serial.println("Erro ao ler a umidade!");
  else payload += "\"UmidadeAr\": " + String(humidity) + ", ";

  // Internals
  if (isnan(intTemp_celsius)) Serial.println("Erro ao ler a temp_int!");
  else payload += "\"TemperaturaInterna\": " + String(intTemp_celsius) + ", ";

  payload += "\"ForcaSinal\": " + String(WiFi.RSSI()) + ", ";
  payload += "\"ssid\": \"" + String(WiFi.SSID()) + "\", ";
  payload += "\"bssid\": \"" + String(WiFi.BSSIDstr()) + "\",";
  // Last
  payload += "\"type\": \""+ String(board_info) +"\"";
  payload += "}";
  Serial.printf("Payload %s\n", payload.c_str());

  if (endpoint1 != nullptr) sendPayloadTo(endpoint1, payload);
  else Serial.println("NULL ENDPOINT 1 - DO NOT SEND");
  
  if (endpoint2 != nullptr) sendPayloadTo(endpoint2, payload);
  else Serial.println("NULL ENDPOINT 2 - DO NOT SEND");
}
void sendPayloadTo(const char* endpoint, String payload) {
  Serial.printf("Sendind data to: %s\n", endpoint);
  
  HTTPClient http;
  http.begin(endpoint);
  http.addHeader("Content-Type", "application/json");
  http.addHeader("x-key", api_key);

  int httpResponseCode = http.POST(payload);

  if (httpResponseCode > 0) {
    Serial.printf("HTTP Response code: %d\n", httpResponseCode);
  } else {
    Serial.printf("Failed to send data: %s\n", http.errorToString(httpResponseCode).c_str());
  }

  http.end();
}

/* Internals */
float readInternalTemp(){
  uint8_t raw_int_temp;

  for(int i = 0; i < 10; i++) {
    raw_int_temp = temprature_sens_read();
    //Serial.printf("temprature_sens_read: %d\n", raw_int_temp);

    if(raw_int_temp != 128)  break;
    delay(10);
  }

  return raw_int_temp == 128 ? NAN : (raw_int_temp - 32) / 1.8f;
}

/* Helpers */ 
float mapfloat(float x, float in_min, float in_max, float out_min, float out_max)
{
  return (x - in_min) * (out_max - out_min) / (in_max - in_min) + out_min;
}

void checkSleep(){
  if(sleep_after == 0) return; // do not sleep
  if(sleep_for == 0) return; // do not sleep

  unsigned long tempoDecorrido = millis();

    Serial.print("[DBG SLP] TC: ");
    Serial.print(tempoDecorrido);
    Serial.print(" SA: ");
    Serial.print(sleep_after);
    Serial.print(" SF: ");
    Serial.print(sleep_for);
    Serial.println();
  
  if (tempoDecorrido >= sleep_after * 1000) {
    Serial.println("Entering deep sleep");
    delay(1000);
    esp_deep_sleep(sleep_for * 1000000); // 3 minutos em microsegundos
  }
}

void setup() {
  // Seta Pinos
  pinMode(ADC_PIN, INPUT);
  pinMode(PULSE_PIN, INPUT);
  pinMode(LED_STATUS, OUTPUT);
  pinMode(LED_IO, OUTPUT);

  digitalWrite(LED_STATUS, HIGH); // Começa Boot
  // Serial Boot
  Serial.begin(115200);
  delay(1000);
  Serial.printf("\n\nBoot: %s\n", board_info);
  
  // Objetos
  dht.begin();

  digitalWrite(LED_STATUS, LOW); // Finaliza Boot
}

void loop() {
  connectToWiFi();
  //sendData();  
  disconnectWiFi();

  //delay(120000); // A cada 2 minutos
  
  checkSleep(); // Se entrar em sleep, não retorna daqui

  delay(10 * 1000); // wait 10s
}

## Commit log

2024-06-30 Migração do Harware
    [EspLora.kicad_pcb, EspLora.kicad_sch]
2024-06-30 Migração do site de dados
2024-07-30 Versão 1.2
    Altera GPIO do VBat
    Adiciona PullUp DHT
    Adiciona Conector para USS
    Adiciona Leds de Status
    [RiMon.kicad_pcb, RiMon.kicad_sch]
2024-08-06 Suporte para placa Dev1.1
    [Suporte.FCStd, Suporte.stl]
2024-09-24 Adiciona Models de Precipitação
2024-09-25 Sensores de primeira geração não tem pressão
2024-11-20 Progresso alterações
    [RiMon.kicad_pcb, RiMon.kicad_sch]
2024-11-20 Finaliza traces v1.2
    [RiMon.kicad_pcb]
2024-11-25 Hardware v1.3
    [RiMon.kicad_pcb, RiMon.kicad_sch]
2024-11-26 v1.3 conectado e organizado
    [RiMon.kicad_pcb, RiMon.kicad_sch]
2024-11-26 Limpeza geral
    [RiMon.kicad_pcb, RiMon.kicad_sch]
2024-11-28 Finaliza Design
    [RiMon.kicad_pcb]
2024-11-28 Ajustes fabricação
    [RiMon.kicad_pcb, RiMon.kicad_sch]
2024-12-01 Fixa cores para estações conhecidas
2024-12-02 Adiciona formatação de valor
2024-12-06 Corrige gráfico de nível do Rio
2024-12-07 Agregador de valores
2024-12-07 Adiciona Round que suporta null
2024-12-08 Adiciona agregador de dados
2024-12-08 Trás script de gráfico para dentro
2024-12-10 Retorna NULL ao invés de zero
2024-12-14 Upload de imagem
2024-12-14 Ajusta para UTC
2024-12-14 Nova fórmula de último
2024-12-14 Ajuste de horário no Live
2024-12-15 Altera filtro de null
2024-12-17 Adiciona listagem de estações
2025-01-06 Adiciona suporte
    [Suporte_tubular_USS.scad]
2025-02-10 Suporte EspCam
    [SuporteEspCam.FCStd, SuporteEspCam_v0.FCStd, SuportePlaca_v1.3.FCStd]
2025-02-10 Suporte 18650
    [SuporteBateria18650.FCStd]
2025-02-10 Adiciona página de manutenção
2025-02-24 Ajuste de CSS
2025-02-24 Atualizações modelos
    [SuporteCaixa_190x150x90_Tubo.FCStd, SuporteEspCam.FCStd, SuportePlaca_v1.3.FCStd]
2025-03-26 Ajuste de horário e gráficos
2025-03-26 Permite clicar no gráfico da estação para detalhar
2025-04-11 Adiciona SuporteLoRa
    [SuporteLoRa.FCStd, SuporteLoRa_18650.FCStd, SuporteLoRa_18650_v2.FCStd]
2025-04-11 Adiciona Cache para lastHourly
2025-04-15 Corrige tela de manutenção
2025-04-16 Log de dados
2025-04-18 Migra identificação para Source
2025-04-18 Aumenta limite da tela de detalhes
2025-04-25 Altera resposta para "10min"
2025-04-25 Ajuste dos pontos para melhor visibilidade
2025-04-25 Ajuste área de click
2025-04-25 Gráfico de chuva
2025-04-28 Corrige exibição de zeros
2025-04-28 Converte gráfico para mm/h
2025-04-29 Gráfico de barras
2025-04-29 Corrige agregador de NULL
2025-04-29 Gráfico de barras apenas para chuva
2025-06-06 Atualiza /live para horário local
2025-06-17 Migra nova para maint
2025-06-18 Ajutes de texto
2025-06-18 Adiciona gráfico de chuva no detalhamento
2025-06-18 Adiciona Logging de acesso
2025-06-19 Atualiza Archiver para nome
2025-06-21 Corrige offset de datas
2025-06-21 Refatora home para celular
2025-06-22 Adiciona encaixe parafuso
    [SuportePlaca_v1.3.FCStd]
2025-06-22 Troca OnClick para a-href
2025-06-27 Update README.md
    Correção de Typos
2025-06-29 Extrai imagem da coinos para fora da Home
2025-06-29 Migra para SVG
2025-06-29 Salvar agregado para vazio
2025-06-30 Arquivos 3D
    [Pluv_v0-Base.stl, Pluv_v0-Bucket.stl, Pluv_v0-Funnel.stl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]
2025-06-30 Adiciona data/hora dos dados de previsão
2025-06-30 Ediciona edição de Estação
2025-06-30 Refatora exibição de listagem
2025-07-01 Muda exibição de vento
2025-07-02 Altera intervalo da previsão para <2/d
2025-07-02 Altera sequenciamento de leitura das estações externas
2025-07-02 Altera casas decimais para T<10
2025-07-02 Testa duas opções de geração em Build
2025-07-02 Migra /home.html para Index
2025-07-02 Implementa edição de estação com reset de Key
2025-07-04 Troca externas de 4/h para 5/h
2025-07-04 Adiciona gráfico de pressão no detalhamento
2025-07-06 Corrige gráfico de bateria
2025-07-15 Adiciona endpoint para weather extendido
2025-07-16 Correções de conversão UTC
2025-07-16 Correção de Id
2025-07-16 Forçar geração de dados Hourly
2025-07-17 Corrige gráfico de precipitação
2025-07-25 Adiciona calibração para ignorar a raíz
2025-07-27 Muda previsão estendida para vários dias
2025-07-27 Retorna BE01 para Index
2025-07-27 Desativa probabilidade de chuva na home
2025-07-28 Corrige valor de debug
2025-08-03 Ajusta faixa do gráfico para incluir a hora atual
2025-08-04 Remove ferramenta de ocultar alerta
2025-08-04 Atualiza revisão do index para r=5
2025-08-11 Adiciona NonceCheck para UpController
2025-08-14 Adicionar detalhes de versão
2025-08-14 Adiciona base de sincronia entre servidores
2025-08-18 Renomeia componentes INDEX para RSRL
2025-08-18 Migra INDEX para roteador
2025-08-19 Melhora exibição de estações sincronizadas
2025-08-19 Implementa código de região
2025-08-22 Troca CE01 do mapa para CE02
2025-09-20 Ajusta calibração braço de medição
2025-12-09 Aviso de manutenção
2025-12-29 Ajustes para telas pequenas
2025-12-29 Adiciona aviso de manutenção
2026-01-18 Adiciona gráfico de chuva no Morro Grande
2026-01-18 Adiciona ID da MG01 na lista de Chuva
2026-01-18 Refatora avisos de compilador
2026-03-30 Corrige bug em transações que não são divisíveis por 4
2026-03-31 Corrige busca de estação vazia
2026-08-02 Índice de risco numérico (1-10), card ACISA, SVG no botão de fechar + diversas melhorias visuais (#9)
    * docs: aponta caminhos corretos (Website/Dados/Web.Data/wwwroot/serra*) e regras do Rafael no spec
    * docs: plano de implementação do índice de risco numérico (1-10)
    * feat(risco): adiciona tabelas de ancora e escala() pro indice 1-10
    * fix(risco): rampa suave no bonus de nowcast, renomeia escala->escalaRisco, remove parametro redundante, guarda NaN pro lado seguro
    * feat(risco): expoe F.indiceAgora/indiceFuturo/indice em cityFlood()
    * refactor(risco): computeRisk le indice pronto de cityFlood(), sem logica duplicada
    * feat(risco): selo do topo mostra indice 1-10 em vez de categ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
2026-08-08 serra: destaca dia e noite no gráfico de chuva (#10)
    * feat(risco): selo do topo mostra indice 1-10 em vez de categoria em palavra
    * feat(risco): card 'Enchente na c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
2026-08-09 serra: alerta de vento usa rajada (não vento sustentado) + badge de vento forte (#11)
    *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
2026-08-09 fix(serra): restaura alerta de vento por rajada, perdido no merge do #11 (#12)
    O merge do PR #11 (093b544) resolveu um conflito entre os próprios
    commits da branch escolhendo hunks antigos: as 5 telas que liam
    ventoRajada (rajada, validada contra o vendaval real de 06-07/08/2026,
    54-58 km/h) voltaram a ler ventoVelocidade (vento sustentado, que no
    mesmo vendaval mal saiu de 22-23 km/h — nunca cruzaria o limiar de
    40 km/h). Prova ao vivo: no forecast atual, rajada chegou a 43,9 km/h
    enquanto o sustentado não passou de 16,4 km/h — o alerta ficaria
    permanentemente mudo com o bug.
    Também sumiu, no mesmo merge, o badge de vento no card do dia
    (fc-days): a variável `vento`/windSvg() parou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
